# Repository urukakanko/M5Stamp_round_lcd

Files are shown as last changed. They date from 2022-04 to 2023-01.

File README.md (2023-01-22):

# M5Stampラウンド液晶モジュール

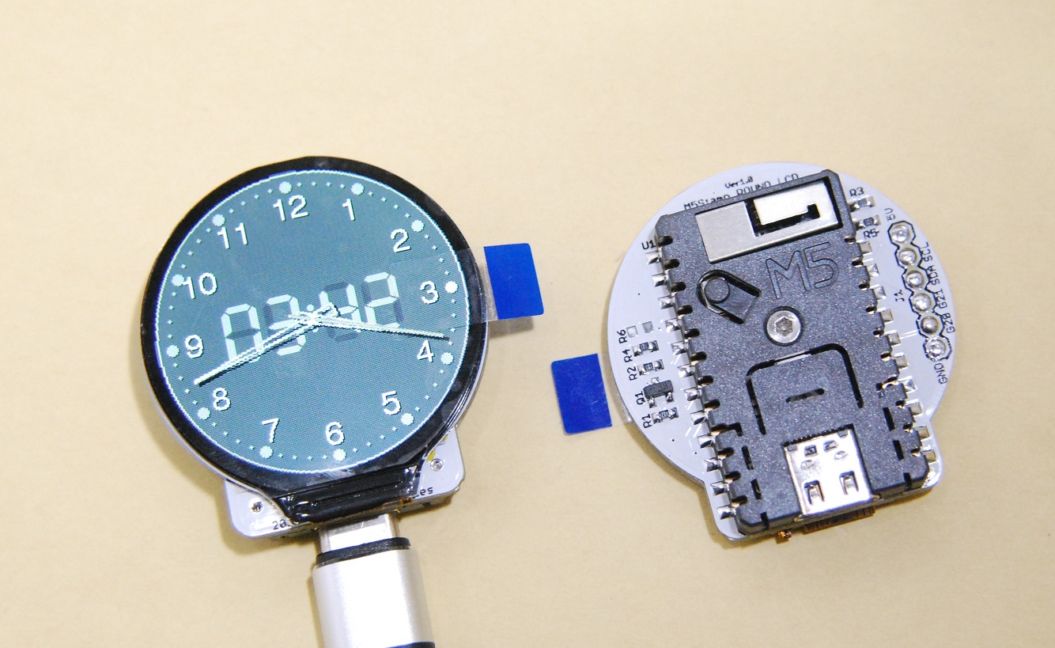
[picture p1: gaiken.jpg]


M5Stampを使用して1.28インチ240ｘ240ドットの円形液晶を駆動する基板モジュールです。

円形液晶の裏にM5Stampを配置することで、とても小さくスリムな形状になりました。

円形液晶にはGC9A01というコントローラーが使用されていますが、対応したグラフィックライブラリが数種類公開されています。

本モジュールは「グラフィックライブラリの使い方を理解して液晶モジュールを駆動出来る人」をターゲットにしております。

# <span style="color: red;">注意！！（必ずお読み下さい）</span>

本品は基本的な電子回路の仕組みを理解した方を対象とした、電子部品がむき出しの半完成キットです。
電子部品は電源電圧や極性を間違えたり、部品を破損させたり部品端子をショートさせた場合、発熱・発煙・発火に至る場合もあります。
間違った使い方をすると危険である事を理解された方のみご使用ください。
趣味の電子工作向けに製作しておりますので、製品への組込みや日常生活へ組込んでのご使用はお控え下さい。

# 形状および回路図

以下に外形イメージを示します

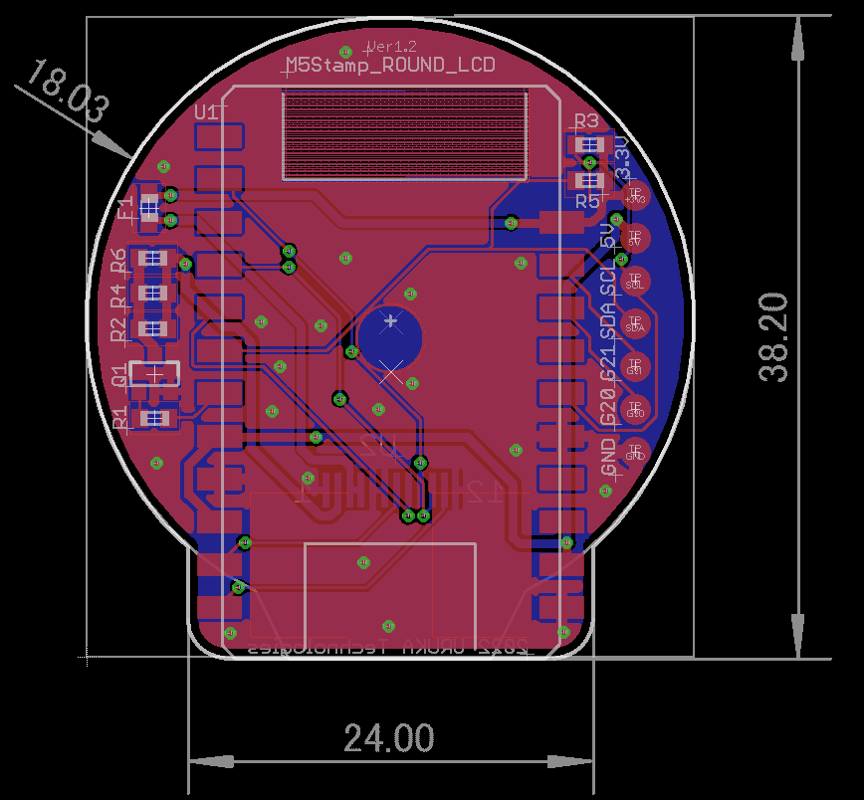
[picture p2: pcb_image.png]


以下に回路図を示します　現在最新は基板Ver1.2です

　基板Ver1.0の回路図などはこちら⇒
https://github.com/urukakanko/M5Stamp_round_lcd/tree/main/Ver1.0

　基板Ver1.1の回路図などはこちら⇒
https://github.com/urukakanko/M5Stamp_round_lcd/tree/main/Ver1.1

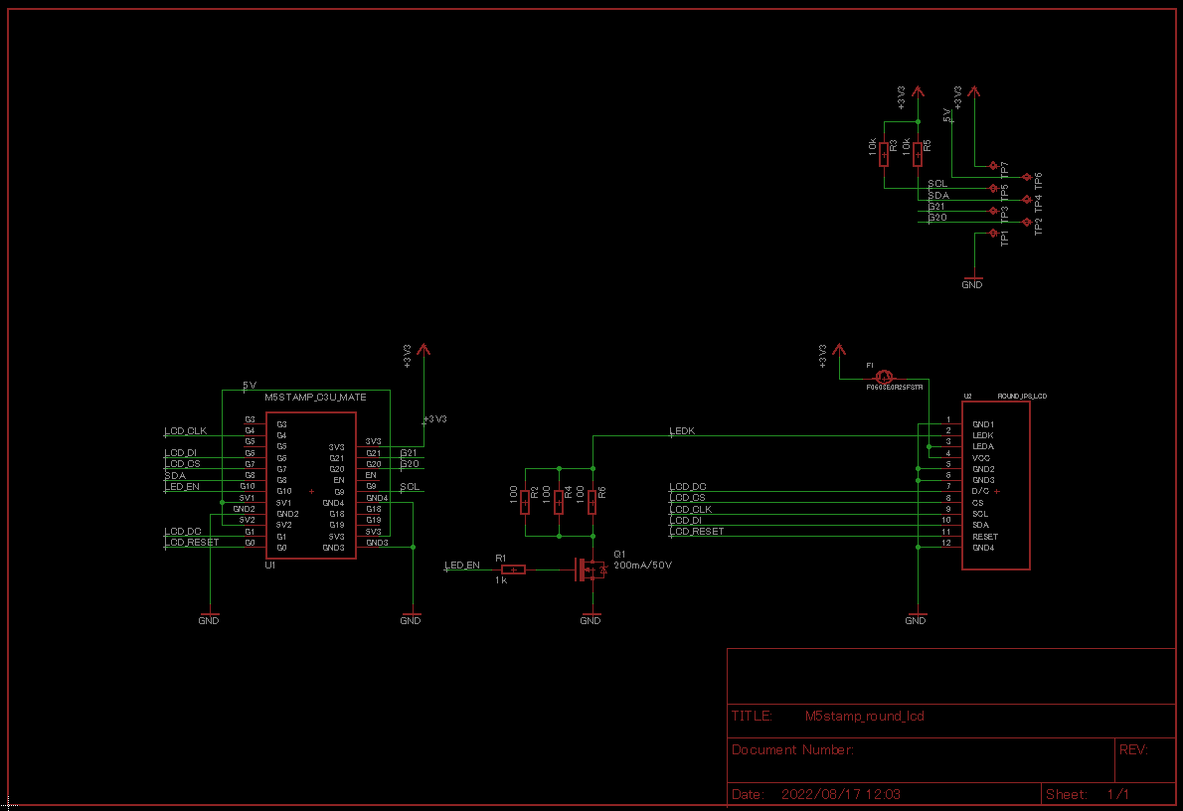
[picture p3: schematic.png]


# ピンアサイン

M5Stamp とLCDの制御信号とのピン接続は以下となります。

- SCLK:G4

- MOSI:G6

- DC:G1

- CS:G7

- RST:G0

- バックライト:G10　バックライトLEDのPIN設定は必ず行ってください。ハイインピーダンスとなった場合バックライトが不安定になります。

また、I2C接続などを想定した外部接続端子があります

注意：リード線をハンダ付けするパットとして使用します　コネクタやピンヘッダは挿せません。　基板Ver1.0ではスルーホールになっていますが無理やり挿すとピン先がLCDにぶつかって破損したりショートする恐れがあります。
また、6PINおよび7PINはセンサーなど小型周辺モジュールを駆動するための電源出力端子です。本モジュールを駆動するための電源入力としては設計しておりません。

- 1PIN : GND

- 2PIN : G20

- 3PIN : G21

- 4PIN : G8 (I2C SDAを想定)

- 5PIN : G9 (I2C SCLを想定)

- 6PIN : 5V

- 7PIN : 3.3V(基板Ver1.0にはありません　基板Ver1.1より対応) 

「M5Stamp C3U」　および　「 M5Stamp C3」　両方が使用出来る様にG3端子は未接続にしています

# 使用するツールやライブラリ

M5StampのArduino IDEへのインストールは、以下サイトを参考下さい。

https://docs.m5stack.com/en/quick_start/m5core/arduino

グラフィックライブラリについてはlovyanさまのLovyanGFXにて動作確認をしています。

https://github.com/lovyan03/LovyanGFX

他、GC9A01に対応したライブラリが使用可能と考えています。

# そーたメイさま「つくるっち」に対応して頂きました

http://sohta02.web.fc2.com/familyday.html

事前に以下ツールでM5Stampラウンド液晶モジュールにファームウェアを書込んでください

https://sohta02.sakura.ne.jp/release/burnESP.20220930.zip

Chromeブラウザで以下つくるっち画面を開き「拡張機能を追加」から「M5Series」を追加してください

https://sohta02.sakura.ne.jp/tukurutch/

サンプルプログラムは以下です

https://github.com/urukakanko/M5Stamp_round_lcd/blob/main/M5Stamp%E3%82%B5%E3%83%B3%E3%83%97%E3%83%AB_%E3%83%8F%E3%83%83%E3%83%94%E3%83%BC%E3%83%8F%E3%83%AD%E3%82%A6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

USB接続で以下の様に動かす事ができます

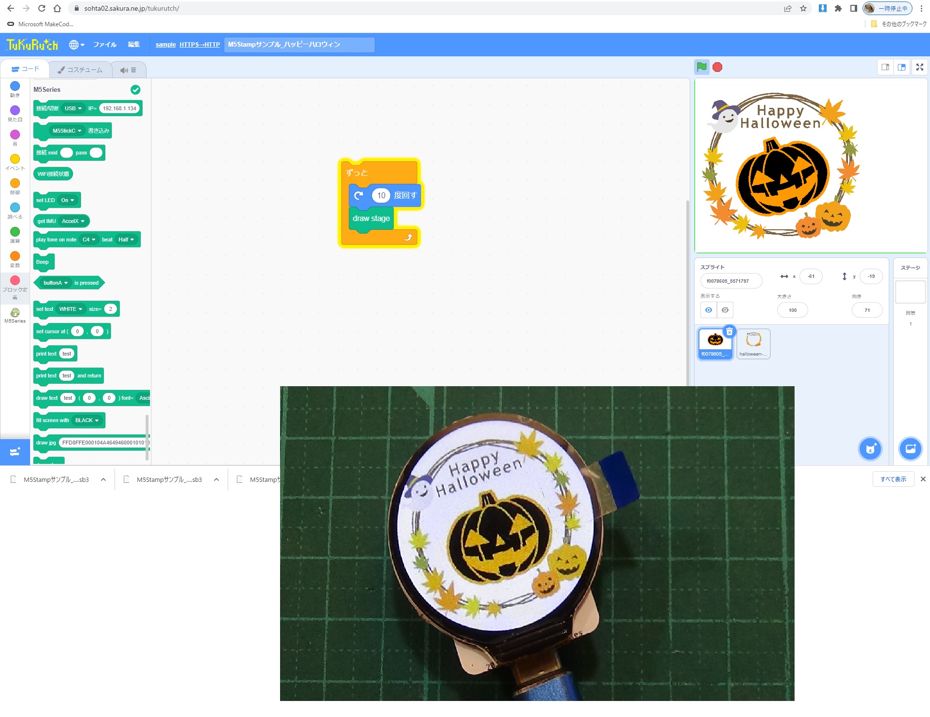
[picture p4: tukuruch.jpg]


もちろんWiFiでの動作も可能です。詳細設定についてはそーたメイさまのサイトを参考にしてください

説明内のファームウェア書き込み操作は不要です【ファームウェア書き込み： マイコンを選択して [書き込み] をクリック】

http://sohta02.web.fc2.com/familyday_app3.html#setup_esp32

# LCD表示動画

https://youtu.be/kj006jx1wdU

# 製作過程動画

https://youtu.be/ezlkv9BLLXo

# 使用例

スマートウォッチはもちろん、アイコン表示でカードフォルダー代わり

ロボットに顔写真を表示すると、とても味のある雰囲気に・・・

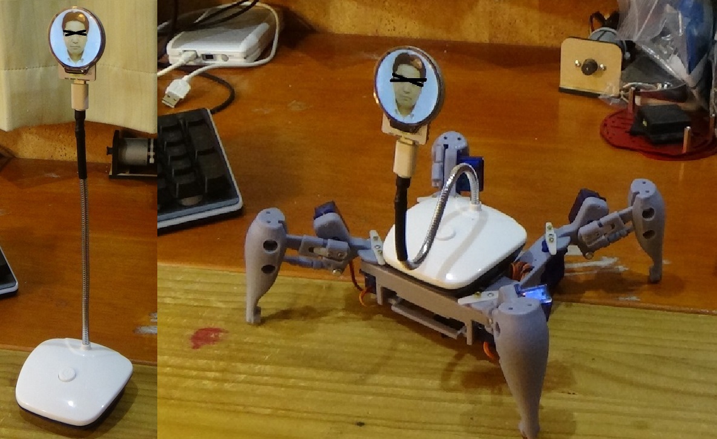
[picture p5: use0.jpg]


AMG8833と組合わせると温度虫眼鏡も作れます　動画はこちら
https://youtu.be/yjvwYW8tv_Q
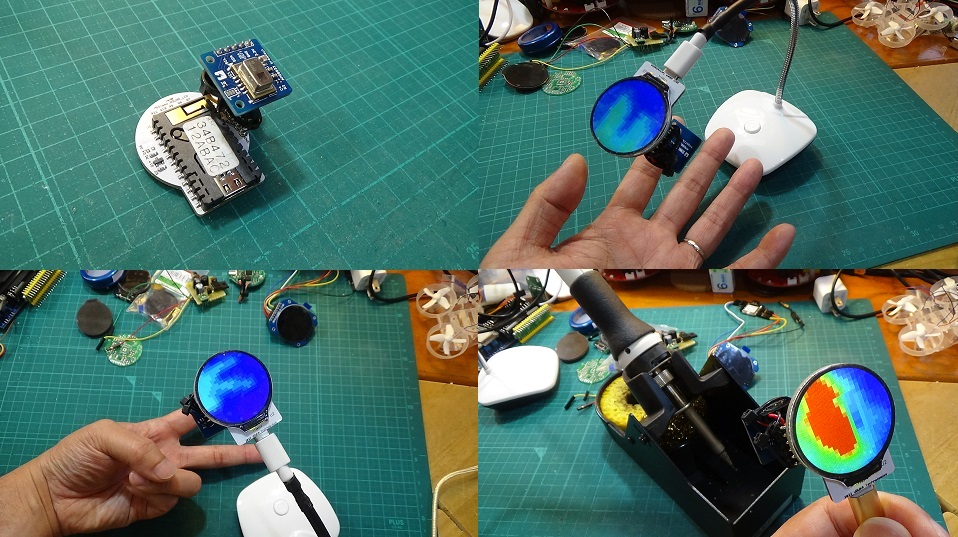
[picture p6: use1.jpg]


AMG8833サーマルカメラの作り方をまとめました　とても便利ですので興味がある方はご覧ください

https://github.com/urukakanko/M5Stamp_round_lcd/tree/main/thermal_cam_demo

カラフルな液晶バッジ

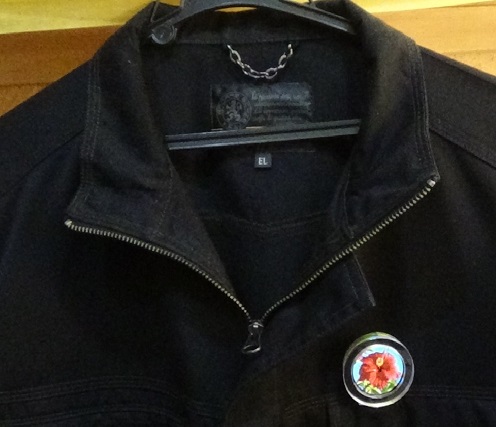
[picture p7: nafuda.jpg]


# スイッチサイエンスマーケットプレイスで販売しています
M5Stamp実装版
https://www.switch-science.com/catalog/8098/

M5Stamp未実装版
https://www.switch-science.com/catalog/8099/

# 製作者

ウルカテクノロジー
Hiroyuki Sunagawa

https://www.facebook.com/URUKA-Technologies-105478404379918

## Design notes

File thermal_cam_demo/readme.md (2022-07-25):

# M5Stampラウンド液晶モジュール作例　AMG8833サーマルカメラ

電子工作をしていると異常発熱する部品があったりしてサーモグラフィーで観察したくなる場合があります。

でもそんな高級品はなかなか買えません。そんなときAMG8833を使用した簡易サーマルカメラが役に立ちます。

AMG8833はパナソニック製の８ｘ８セルのサーマルセンサーです。I2Cインターフェースで制御します。

なお、AMG8833自体を詳しく弄りたい方はこちらを購入するとよいと思います。

https://www.switch-science.com/catalog/3498/

## ハードの作り方

AMG8833モジュールを入手します。スイッチサイエンスや秋月電子で入手が可能です。

今回はスイッチサイエンスで販売しているモジュールが手元にあったのでそれで作ってみます

以下の様にAMG8833モジュールにリード線をハンダ付けします

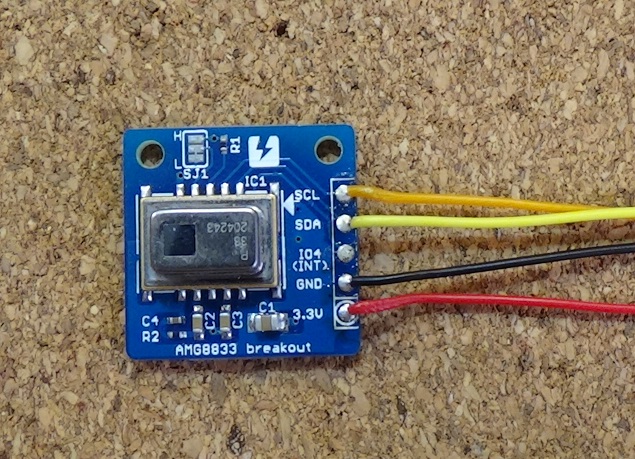
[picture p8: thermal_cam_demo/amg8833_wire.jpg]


必要な接続線は、３．３V、GND、SDA、SCL　の４本です。リード線を使ってAMG8833モジュールとM5Stampラウンド液晶モジュールをつなげます。

裏面を念のためにテープ等で絶縁しています。ポリイミドテープ（カプトンテープ）がお勧めです

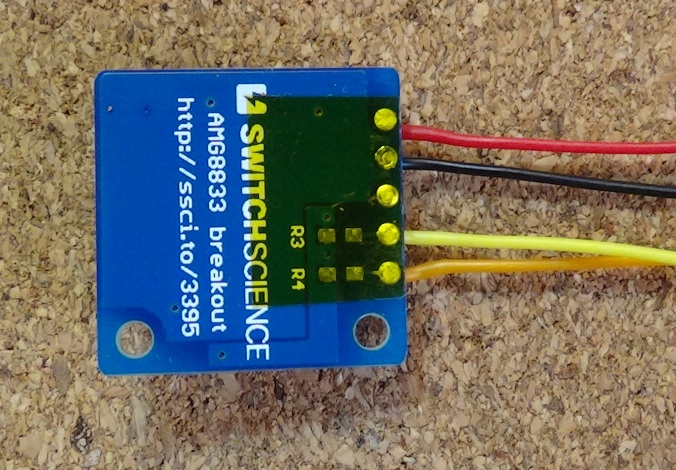
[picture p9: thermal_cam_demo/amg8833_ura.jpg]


リード線の反対側をM5Stampラウンド液晶モジュールに結線します。

M5Stampラウンド液晶モジュールVer1.0の場合は3.3Vパットを出していないので、M5Stampの端子に直接リード線をハンダ付けします。

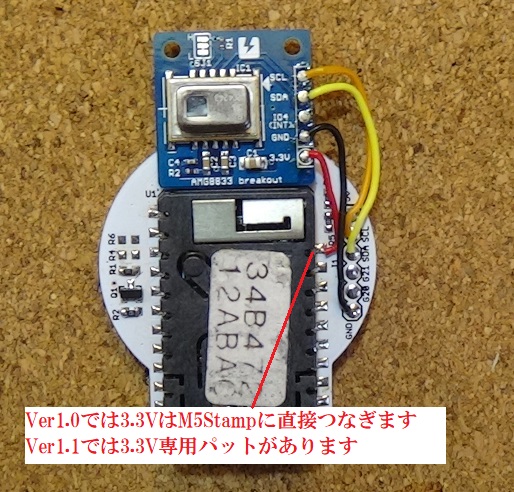
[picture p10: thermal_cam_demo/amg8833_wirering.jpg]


M5Stampに両面テープを貼り、そこにAMG8833モジュールを貼り付けます

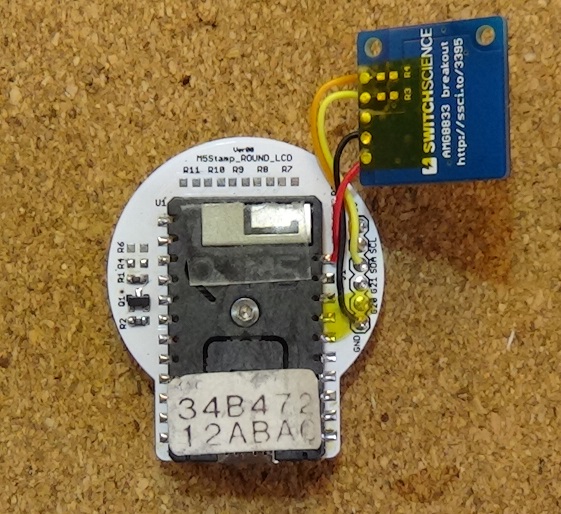
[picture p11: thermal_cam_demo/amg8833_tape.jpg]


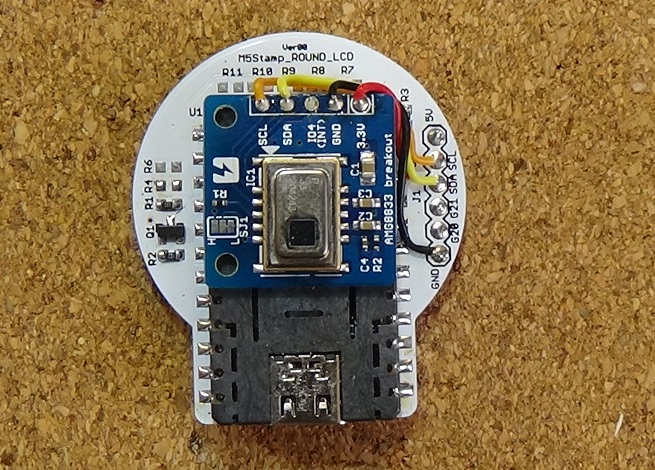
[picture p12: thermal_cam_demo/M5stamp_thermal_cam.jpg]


## プログラミング

Arduino IDEでプログラミングします。

今回AMG8833を駆動させるために、Adafruit AMG88xx Library　を使用します。

スケッチ⇒ライブラリをインクルード⇒ライブラリを管理　でライブラリマネージャを開き　Adafruit AMG88xxで検索します

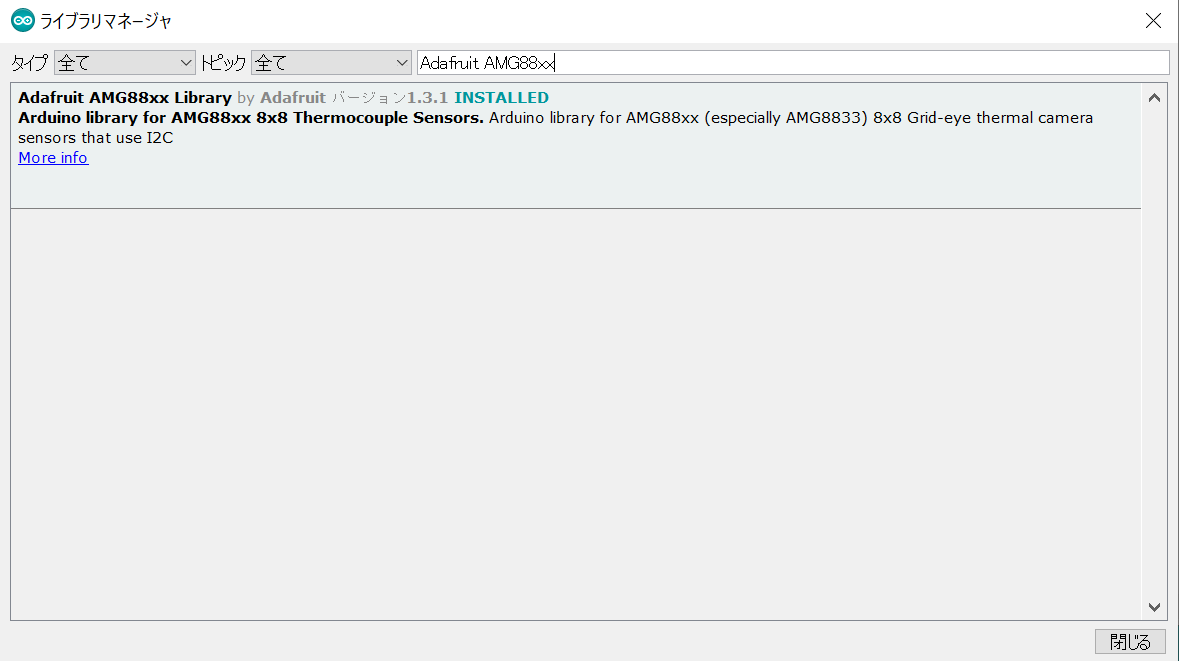
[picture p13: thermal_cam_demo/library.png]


ライブラリをインストールしたら、スケッチの例を呼び出します。

AMG8833をTFT液晶に表示するスケッチ例「thermal_cam_interpolate.ino」が準備されてましたので使用しました。

ただし使用する液晶が異なる事、表示位置のオフセット、補完内容の変更などがあるので修正が必要となります。

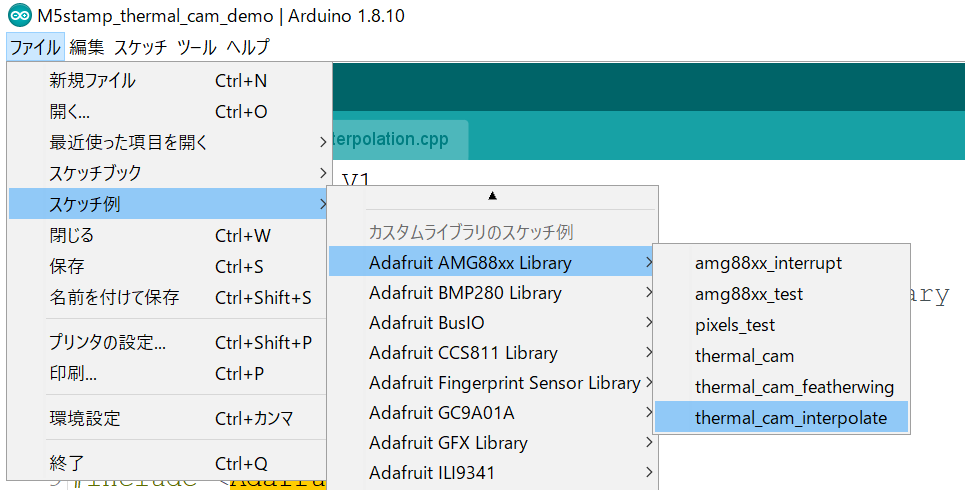
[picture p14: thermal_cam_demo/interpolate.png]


修正後のソースコードは以下に保存しています。

https://github.com/urukakanko/M5Stamp_round_lcd/tree/main/thermal_cam_demo/M5stamp_thermal_cam_demo/M5stamp_thermal_cam_demo

### ソースコード修正のポイント説明

#### 液晶設定と液晶ライブラリについて

スケッチ例では使用する液晶がILI9341になっているのでGC9A01に直す必要があります。

また使用する液晶ライブラリはAdafruit_GFXになっています。　このライブラリでGC9A01も駆動可能なのですが動作速度がちょっと遅かったです。解像度を上げると厳しいので高速化のためにLavyanGFXを使用しています。

ソースコードの先頭から94行目まで入れ替えてあります。

#### 補完について

AMG8833は　8x8(64)セル　のサーマルセンサーなので、このまま映像化しても粗いモザイクの画像になります。そこで補完計算を行い解像の高い画像にしています。

ただし解像度を高くするほど計算に時間がかかってしまいますので表示速度の頃合いをみて40x40にしています。

ソースコード136行目と137行目で設定しています

　#define INTERPOLATED_COLS 40
　#define INTERPOLATED_ROWS 40

#### その他

AMG8833のI2Cアドレスは159行目で0x68に指定しています。必要に応じて0x69にしてください。

液晶の解像度自体が元とは異なるので表示位置を調整しています。

円型液晶は表示領域が狭いので、凡例表示は無しにしました。

## 動作イメージ

100円ショップのLEDライトスタンドを改造したラウンド液晶スタンドに取り付けてみました。

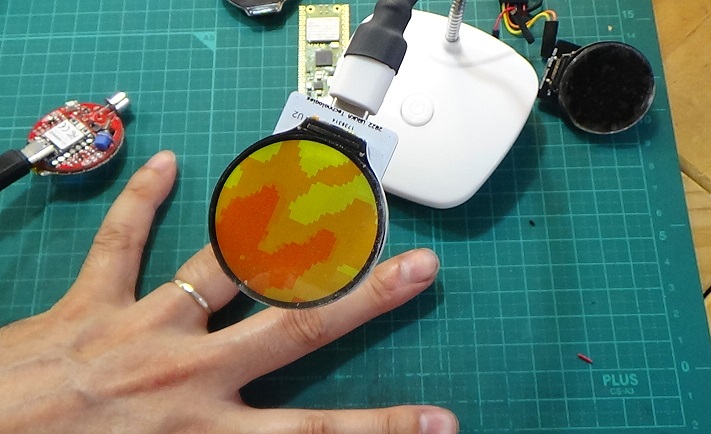
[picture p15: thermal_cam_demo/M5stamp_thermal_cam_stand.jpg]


手の形がなんとか見えるという感じです。

ラズベリーパイ４＋OpenCVで取得できる画像と比較するときついけど、常に持ち歩いて必要な時に即座に使うとか出来るので利便性はとても良いです。

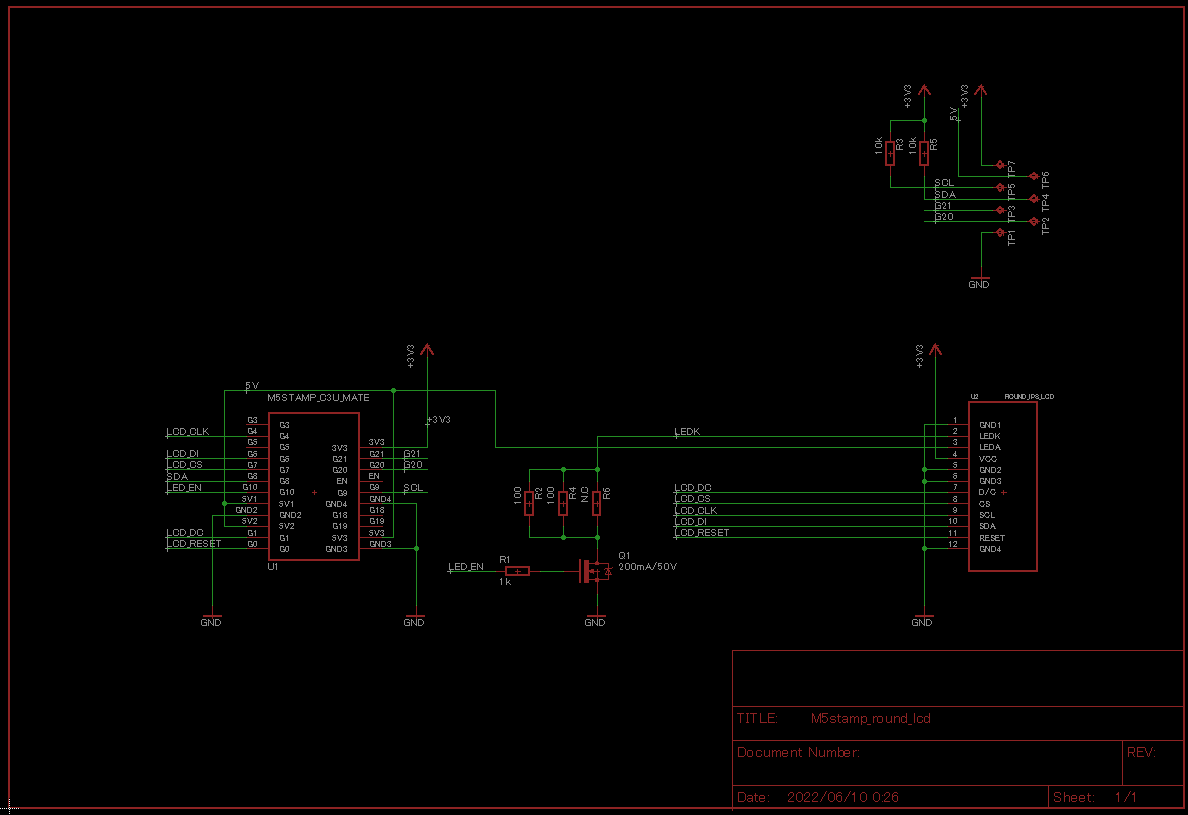
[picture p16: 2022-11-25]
Ver1.1/schematic.png

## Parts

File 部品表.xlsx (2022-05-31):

Part | Value | Device
J1 | 6PIN
Q1 | 200mA/50V | BSS138
R1 | 1k | 1608
R2 | 100 | 1608
R3 | 10k | 1608
R4 | 100 | 1608
R5 | 10k | 1608
R6 | N.C | 1608
U1 | M5STAMP_C3U_MATE | M5STAMP_C3U_MATE
U2 | ROUND_IPS_LCD | ROUND_IPS_LCD

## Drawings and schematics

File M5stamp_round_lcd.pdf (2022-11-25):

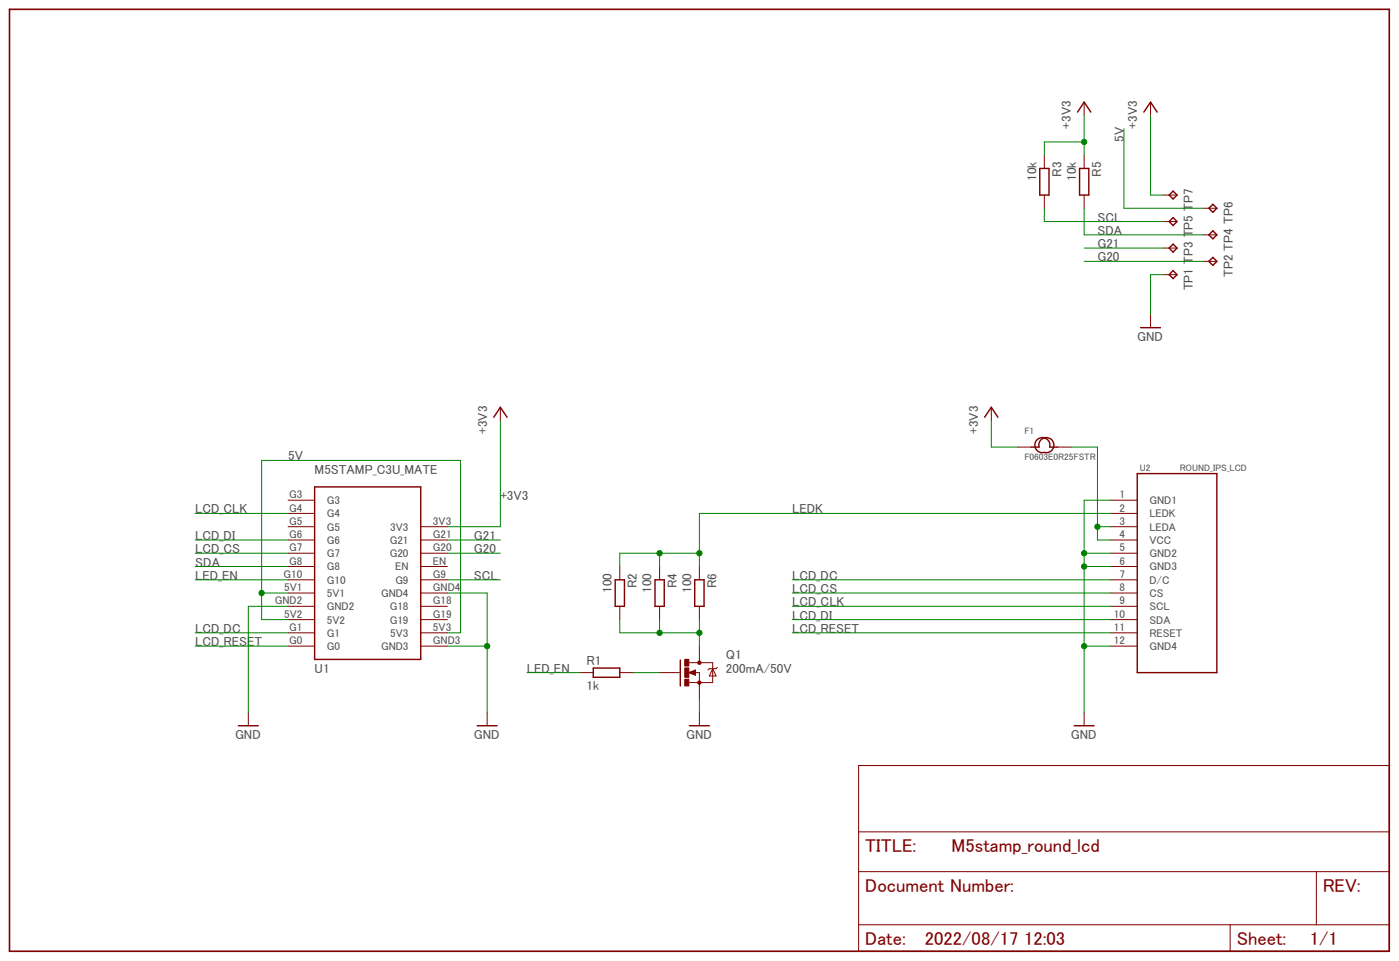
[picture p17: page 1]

Document Number: | REV:

Date: 2022/08/17 12:03 | Sheet: 1/1

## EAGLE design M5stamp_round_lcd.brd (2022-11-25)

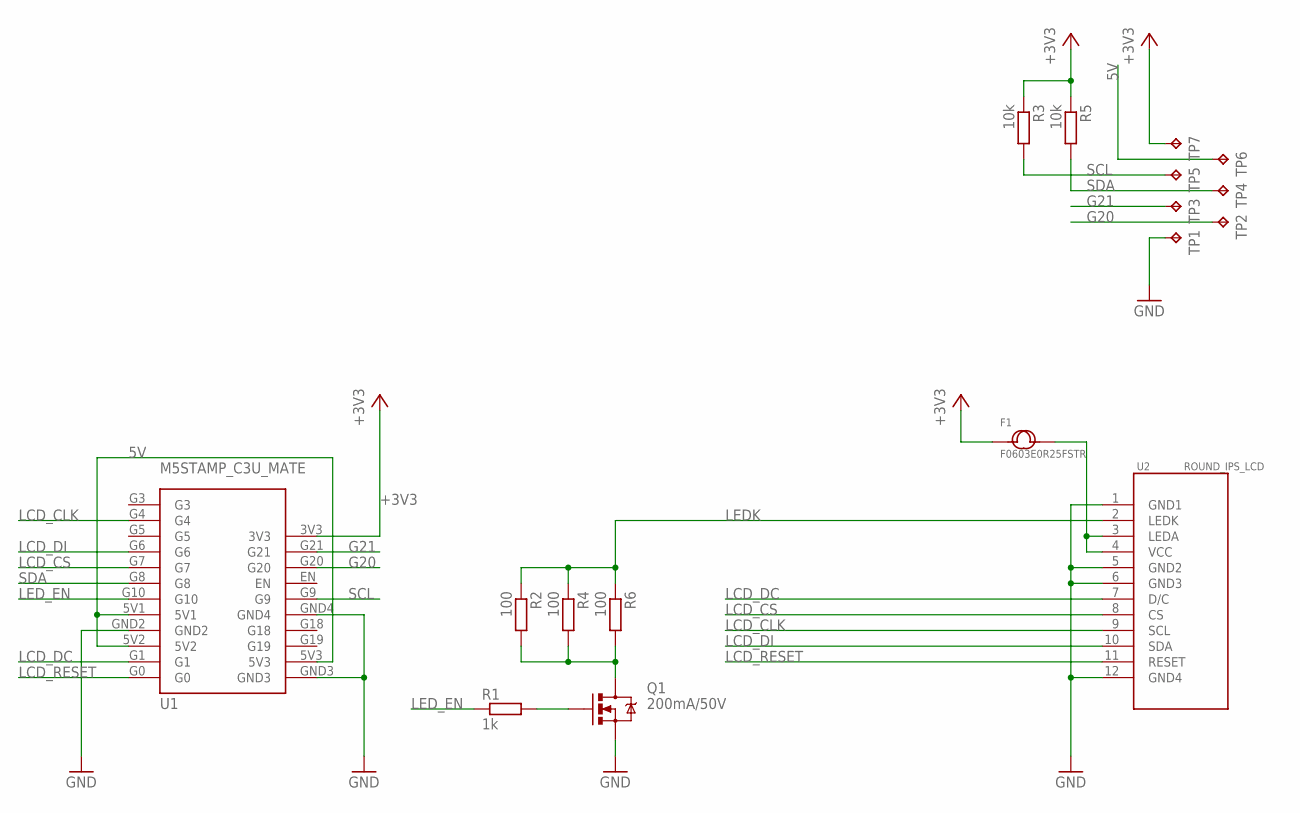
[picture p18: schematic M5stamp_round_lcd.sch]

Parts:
F1: F0603E0R25FSTR; C0603
Q1: 200mA/50V; SOT23-3
R1: 1k; R0603
R2, R4, R6: 100; R0603
R3, R5: 10k; R0603
TP1, TP2, TP3, TP4, TP5, TP6, TP7: TPTP18R; TP18R
U1: M5STAMP_C3U_MATE; M5STAMPC3UMATE
U2: ROUND_IPS_LCD

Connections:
5V: TP6.TP, U1.5V1, U1.5V2, U1.5V3
+3V3: F1.1, R3.1, R5.1, TP7.TP, U1.3V3
G20: TP2.TP, U1.G20
G21: TP3.TP, U1.G21
GND: Q1.2 (S), TP1.TP, U1.GND2, U1.GND3, U1.GND4, U2.1 (GND1), U2.5 (GND2), U2.6 (GND3), U2.12 (GND4)
LCD_CLK: U1.G4, U2.9 (SCL)
LCD_CS: U1.G7, U2.8 (CS)
LCD_DC: U1.G1, U2.7 (D/C)
LCD_DI: U1.G6, U2.10 (SDA)
LCD_RESET: U1.G0, U2.11 (RESET)
LEDK: R2.1, R4.1, R6.1, U2.2 (LEDK)
LED_EN: R1.1, U1.G10
unnamed: Q1.3 (D), R2.2, R4.2, R6.2
unnamed: Q1.1 (G), R1.2
unnamed: F1.2, U2.3 (LEDA), U2.4 (VCC)
SCL: R3.2, TP5.TP, U1.G9
SDA: R5.2, TP4.TP, U1.G8

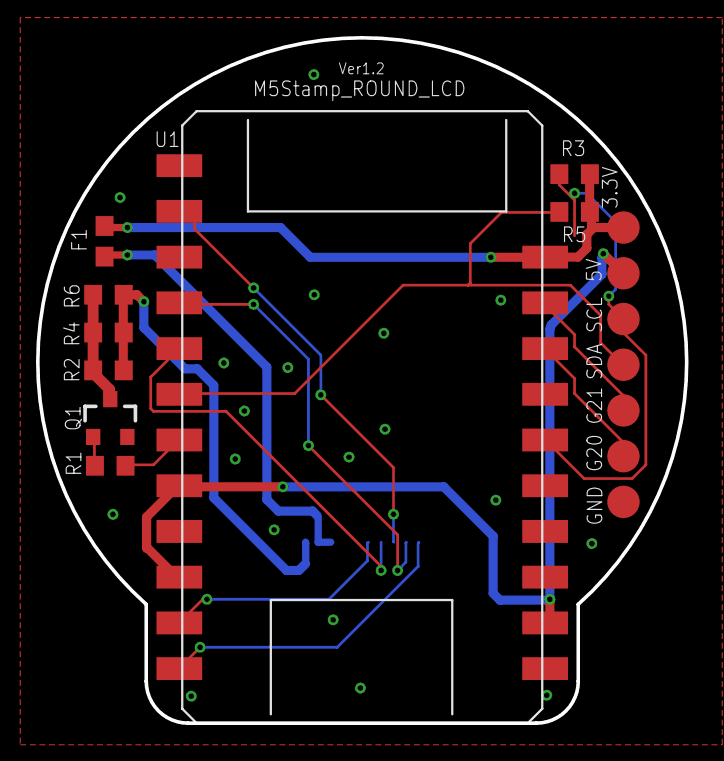
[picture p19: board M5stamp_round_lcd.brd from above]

Board: 2 copper layers, 36.0 x 38.1 mm, 17 parts (1 on the bottom side), 17 nets.

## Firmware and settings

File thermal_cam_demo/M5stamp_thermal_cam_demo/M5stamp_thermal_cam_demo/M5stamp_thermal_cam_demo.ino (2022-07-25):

/***************************************************************************
  This is a library for the AMG88xx GridEYE 8x8 IR camera

  This sketch makes an inetrpolated pixel thermal camera with the 
  GridEYE sensor and a 2.4" tft featherwing:
	 https://www.adafruit.com/product/3315

  Designed specifically to work with the Adafruit AMG8833 Featherwing
          https://www.adafruit.com/product/3622

  These sensors use I2C to communicate. The device's I2C address is 0x69

  Adafruit invests time and resources providing this open source code,
  please support Adafruit andopen-source hardware by purchasing products
  from Adafruit!

  Written by Dean Miller, James DeVito & ladyada for Adafruit Industries.
  BSD license, all text above must be included in any redistribution
 ***************************************************************************/



#define LGFX_USE_V1
#include <LovyanGFX.hpp>

//#include <Adafruit_GFX.h>    // Core graphics library
//#include <SPI.h>
//#include "Adafruit_GC9A01A.h"

#include <Wire.h>
#include <Adafruit_AMG88xx.h>
#define TFT_CS   7
#define TFT_DC   1
#define TFT_CLK  4
#define TFT_DI   6
#define TFT_RST  0
#define TFT_BL  10
#define I2C_SDA  8
#define I2C_SCL  9

//Comment this out to remove the text overlay
//#define SHOW_TEMP_TEXT

//low range of the sensor (this will be blue on the screen)
#define MINTEMP 10

//high range of the sensor (this will be red on the screen)
#define MAXTEMP 30

class LGFX_M5Stamp_SPI_GC9A01 : public lgfx::LGFX_Device
{
lgfx::Panel_GC9A01      _panel_instance;
lgfx::Bus_SPI       _bus_instance;   // SPIバスのインスタンス
lgfx::Light_PWM     _light_instance;
public:
  LGFX_M5Stamp_SPI_GC9A01(void)
  {
    { // バス制御の設定を行います。
      auto cfg = _bus_instance.config();    // バス設定用の構造体を取得します。

// SPIバスの設定
      cfg.spi_host = SPI2_HOST;     // 使用するSPIを選択  ESP32-S2,C3 : SPI2_HOST or SPI3_HOST / ESP32 : VSPI_HOST or HSPI_HOST
      // ※ ESP-IDFバージョンアップに伴い、VSPI_HOST , HSPI_HOSTの記述は非推奨になるため、エラーが出る場合は代わりにSPI2_HOST , SPI3_HOSTを使用してください。
      cfg.spi_mode = 0;             // SPI通信モードを設定 (0 ~ 3)
      cfg.freq_write = 40000000;    // 送信時のSPIクロック (最大80MHz, 80MHzを整数で割った値に丸められます)
      cfg.freq_read  = 16000000;    // 受信時のSPIクロック
      cfg.spi_3wire  = true;        // 受信をMOSIピンで行う場合はtrueを設定
      cfg.use_lock   = true;        // トランザクションロックを使用する場合はtrueを設定
      cfg.dma_channel = SPI_DMA_CH_AUTO; // 使用するDMAチャンネルを設定 (0=DMA不使用 / 1=1ch / 2=ch / SPI_DMA_CH_AUTO=自動設定)
      // ※ ESP-IDFバージョンアップに伴い、DMAチャンネルはSPI_DMA_CH_AUTO(自動設定)が推奨になりました。1ch,2chの指定は非推奨になります。
      cfg.pin_sclk = 4;            // SPIのSCLKピン番号を設定
      cfg.pin_mosi = 6;            // SPIのMOSIピン番号を設定
      cfg.pin_miso = -1;            // SPIのMISOピン番号を設定 (-1 = disable)
      cfg.pin_dc   = 1;            // SPIのD/Cピン番号を設定  (-1 = disable)
     // SDカードと共通のSPIバスを使う場合、MISOは省略せず必ず設定してください。
      _bus_instance.config(cfg);    // 設定値をバスに反映します。
      _panel_instance.setBus(&_bus_instance);      // バスをパネルにセットします。
    }

    { // 表示パネル制御の設定を行います。
      auto cfg = _panel_instance.config();    // 表示パネル設定用の構造体を取得します。
      cfg.pin_cs           =    7;  // CSが接続されているピン番号   (-1 = disable)
      cfg.pin_rst          =    0;  // RSTが接続されているピン番号  (-1 = disable)
      cfg.pin_busy         =    -1;  // BUSYが接続されているピン番号 (-1 = disable)
      // ※ 以下の設定値はパネル毎に一般的な初期値が設定されていますので、不明な項目はコメントアウトして試してみてください。
      cfg.memory_width     =   240;  // ドライバICがサポートしている最大の幅
      cfg.memory_height    =   240;  // ドライバICがサポートしている最大の高さ
      cfg.panel_width      =   240;  // 実際に表示可能な幅
      cfg.panel_height     =   240;  // 実際に表示可能な高さ
      cfg.offset_x         =     0;  // パネルのX方向オフセット量
      cfg.offset_y         =     0;  // パネルのY方向オフセット量
      cfg.offset_rotation  =     0;  // 回転方向の値のオフセット 0~7 (4~7は上下反転)
      cfg.dummy_read_pixel =     8;  // ピクセル読出し前のダミーリードのビット数
      cfg.dummy_read_bits  =     1;  // ピクセル以外のデータ読出し前のダミーリードのビット数
      cfg.readable         =  true;  // データ読出しが可能な場合 trueに設定
      cfg.invert           =  true;  // パネルの明暗が反転してしまう場合 trueに設定
      cfg.rgb_order        = false;  // パネルの赤と青が入れ替わってしまう場合 trueに設定
      cfg.dlen_16bit       = false;  // データ長を16bit単位で送信するパネルの場合 trueに設定
      cfg.bus_shared       =  true;  // SDカードとバスを共有している場合 trueに設定(drawJpgFile等でバス制御を行います)

      _panel_instance.config(cfg);
    }
    { // バックライト制御の設定を行います。（必要なければ削除）
      auto cfg = _light_instance.config();    // バックライト設定用の構造体を取得します。

      cfg.pin_bl = 10;              // バックライトが接続されているピン番号
      cfg.invert = false;           // バックライトの輝度を反転させる場合 true
      cfg.freq   = 44100;           // バックライトのPWM周波数
      cfg.pwm_channel = 3;          // 使用するPWMのチャンネル番号

      _light_instance.config(cfg);
      _panel_instance.setLight(&_light_instance);  // バックライトをパネルにセットします。
    }
    setPanel(&_panel_instance); // 使用するパネルをセットします。
  }
};


//the colors we will be using
const uint16_t camColors[] = {0x480F,
0x400F,0x400F,0x400F,0x4010,0x3810,0x3810,0x3810,0x3810,0x3010,0x3010,
0x3010,0x2810,0x2810,0x2810,0x2810,0x2010,0x2010,0x2010,0x1810,0x1810,
0x1811,0x1811,0x1011,0x1011,0x1011,0x0811,0x0811,0x0811,0x0011,0x0011,
0x0011,0x0011,0x0011,0x0031,0x0031,0x0051,0x0072,0x0072,0x0092,0x00B2,
0x00B2,0x00D2,0x00F2,0x00F2,0x0112,0x0132,0x0152,0x0152,0x0172,0x0192,
0x0192,0x01B2,0x01D2,0x01F3,0x01F3,0x0213,0x0233,0x0253,0x0253,0x0273,
0x0293,0x02B3,0x02D3,0x02D3,0x02F3,0x0313,0x0333,0x0333,0x0353,0x0373,
0x0394,0x03B4,0x03D4,0x03D4,0x03F4,0x0414,0x0434,0x0454,0x0474,0x0474,
0x0494,0x04B4,0x04D4,0x04F4,0x0514,0x0534,0x0534,0x0554,0x0554,0x0574,
0x0574,0x0573,0x0573,0x0573,0x0572,0x0572,0x0572,0x0571,0x0591,0x0591,
0x0590,0x0590,0x058F,0x058F,0x058F,0x058E,0x05AE,0x05AE,0x05AD,0x05AD,
0x05AD,0x05AC,0x05AC,0x05AB,0x05CB,0x05CB,0x05CA,0x05CA,0x05CA,0x05C9,
0x05C9,0x05C8,0x05E8,0x05E8,0x05E7,0x05E7,0x05E6,0x05E6,0x05E6,0x05E5,
0x05E5,0x0604,0x0604,0x0604,0x0603,0x0603,0x0602,0x0602,0x0601,0x0621,
0x0621,0x0620,0x0620,0x0620,0x0620,0x0E20,0x0E20,0x0E40,0x1640,0x1640,
0x1E40,0x1E40,0x2640,0x2640,0x2E40,0x2E60,0x3660,0x3660,0x3E60,0x3E60,
0x3E60,0x4660,0x4660,0x4E60,0x4E80,0x5680,0x5680,0x5E80,0x5E80,0x6680,
0x6680,0x6E80,0x6EA0,0x76A0,0x76A0,0x7EA0,0x7EA0,0x86A0,0x86A0,0x8EA0,
0x8EC0,0x96C0,0x96C0,0x9EC0,0x9EC0,0xA6C0,0xAEC0,0xAEC0,0xB6E0,0xB6E0,
0xBEE0,0xBEE0,0xC6E0,0xC6E0,0xCEE0,0xCEE0,0xD6E0,0xD700,0xDF00,0xDEE0,
0xDEC0,0xDEA0,0xDE80,0xDE80,0xE660,0xE640,0xE620,0xE600,0xE5E0,0xE5C0,
0xE5A0,0xE580,0xE560,0xE540,0xE520,0xE500,0xE4E0,0xE4C0,0xE4A0,0xE480,
0xE460,0xEC40,0xEC20,0xEC00,0xEBE0,0xEBC0,0xEBA0,0xEB80,0xEB60,0xEB40,
0xEB20,0xEB00,0xEAE0,0xEAC0,0xEAA0,0xEA80,0xEA60,0xEA40,0xF220,0xF200,
0xF1E0,0xF1C0,0xF1A0,0xF180,0xF160,0xF140,0xF100,0xF0E0,0xF0C0,0xF0A0,
0xF080,0xF060,0xF040,0xF020,0xF800,};

//Adafruit_GC9A01A tft = Adafruit_GC9A01A(TFT_CS, TFT_DC,TFT_DI,TFT_CLK,TFT_RST);
LGFX_M5Stamp_SPI_GC9A01 tft;

Adafruit_AMG88xx amg;
unsigned long delayTime;

#define AMG_COLS 8
#define AMG_ROWS 8
float pixels[AMG_COLS * AMG_ROWS];

#define INTERPOLATED_COLS 40
#define INTERPOLATED_ROWS 40

float get_point(float *p, uint8_t rows, uint8_t cols, int8_t x, int8_t y);
void set_point(float *p, uint8_t rows, uint8_t cols, int8_t x, int8_t y, float f);
void get_adjacents_1d(float *src, float *dest, uint8_t rows, uint8_t cols, int8_t x, int8_t y);
void get_adjacents_2d(float *src, float *dest, uint8_t rows, uint8_t cols, int8_t x, int8_t y);
float cubicInterpolate(float p[], float x);
float bicubicInterpolate(float p[], float x, float y);
void interpolate_image(float *src, uint8_t src_rows, uint8_t src_cols, 
                       float *dest, uint8_t dest_rows, uint8_t dest_cols);
void setup() {
  pinMode(TFT_BL,OUTPUT);
  digitalWrite(TFT_BL,HIGH);
  Serial.begin(115200);  
  Serial.println("\n\nAMG88xx Interpolated Thermal Camera!");

  tft.init();
  //tft.begin();
  tft.setRotation(0);
  tft.fillScreen(TFT_BLACK);

  Wire.begin(I2C_SDA,I2C_SCL);  
  if (!amg.begin(0x68)) {    
    Serial.println("Could not find a valid AMG88xx sensor, check wiring!");
    //while (1) { delay(1); }
  } 
  Serial.println("-- Thermal Camera Test --");
}

void loop() {
  //read all the pixels
  amg.readPixels(pixels);

  Serial.print("[");
  for(int i=1; i<=AMG88xx_PIXEL_ARRAY_SIZE; i++){
    Serial.print(pixels[i-1]);
    Serial.print(", ");
    if( i%8 == 0 ) Serial.println();
  }
  Serial.println("]");
  Serial.println();

  float dest_2d[INTERPOLATED_ROWS * INTERPOLATED_COLS];

  int32_t t = millis();
  interpolate_image(pixels, AMG_ROWS, AMG_COLS, dest_2d, INTERPOLATED_ROWS, INTERPOLATED_COLS);
  Serial.print("Interpolation took "); Serial.print(millis()-t); Serial.println(" ms");

  uint16_t boxsize = min(tft.width() / INTERPOLATED_COLS, tft.height() / INTERPOLATED_COLS);
  
  drawpixels(dest_2d, INTERPOLATED_ROWS, INTERPOLATED_COLS, boxsize, boxsize, false);

  //delay(50);
}

void drawpixels(float *p, uint8_t rows, uint8_t cols, uint8_t boxWidth, uint8_t boxHeight, boolean showVal) {
  int colorTemp;
  for (int y=0; y<rows; y++) {
    for (int x=0; x<cols; x++) {
      float val = get_point(p, rows, cols, x, y);
      if(val >= MAXTEMP) colorTemp = MAXTEMP;
      else if(val <= MINTEMP) colorTemp = MINTEMP;
      else colorTemp = val;
      
      uint8_t colorIndex = map(colorTemp, MINTEMP, MAXTEMP, 0, 255);
      colorIndex = (uint8_t)constrain((int16_t)colorIndex, (int16_t)0, (int16_t)255);
      //draw the pixels!
      uint16_t color;
      color = val * 2;
      tft.fillRect(boxWidth * x, boxHeight * y, boxWidth, boxHeight, camColors[colorIndex]);        
      if (showVal) {
        tft.setCursor(boxWidth * y + boxWidth/2 - 12, 40 + boxHeight * x + boxHeight/2 - 4);
        tft.setTextColor(TFT_WHITE);  tft.setTextSize(1);
        tft.print(val,1);
      }
    } 
  }
}

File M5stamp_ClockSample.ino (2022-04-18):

#define LGFX_USE_V1
#include <LovyanGFX.hpp>

class LGFX_M5Stamp_SPI_GC9A01 : public lgfx::LGFX_Device
{
lgfx::Panel_GC9A01      _panel_instance;
lgfx::Bus_SPI       _bus_instance;   // SPIバスのインスタンス
lgfx::Light_PWM     _light_instance;
public:
  LGFX_M5Stamp_SPI_GC9A01(void)
  {
    { // バス制御の設定を行います。
      auto cfg = _bus_instance.config();    // バス設定用の構造体を取得します。

// SPIバスの設定
      cfg.spi_host = SPI2_HOST;     // 使用するSPIを選択  ESP32-S2,C3 : SPI2_HOST or SPI3_HOST / ESP32 : VSPI_HOST or HSPI_HOST
      // ※ ESP-IDFバージョンアップに伴い、VSPI_HOST , HSPI_HOSTの記述は非推奨になるため、エラーが出る場合は代わりにSPI2_HOST , SPI3_HOSTを使用してください。
      cfg.spi_mode = 0;             // SPI通信モードを設定 (0 ~ 3)
      cfg.freq_write = 40000000;    // 送信時のSPIクロック (最大80MHz, 80MHzを整数で割った値に丸められます)
      cfg.freq_read  = 16000000;    // 受信時のSPIクロック
      cfg.spi_3wire  = true;        // 受信をMOSIピンで行う場合はtrueを設定
      cfg.use_lock   = true;        // トランザクションロックを使用する場合はtrueを設定
      cfg.dma_channel = SPI_DMA_CH_AUTO; // 使用するDMAチャンネルを設定 (0=DMA不使用 / 1=1ch / 2=ch / SPI_DMA_CH_AUTO=自動設定)
      // ※ ESP-IDFバージョンアップに伴い、DMAチャンネルはSPI_DMA_CH_AUTO(自動設定)が推奨になりました。1ch,2chの指定は非推奨になります。
      cfg.pin_sclk = 4;            // SPIのSCLKピン番号を設定
      cfg.pin_mosi = 6;            // SPIのMOSIピン番号を設定
      cfg.pin_miso = -1;            // SPIのMISOピン番号を設定 (-1 = disable)
      cfg.pin_dc   = 1;            // SPIのD/Cピン番号を設定  (-1 = disable)
     // SDカードと共通のSPIバスを使う場合、MISOは省略せず必ず設定してください。
      _bus_instance.config(cfg);    // 設定値をバスに反映します。
      _panel_instance.setBus(&_bus_instance);      // バスをパネルにセットします。
    }

    { // 表示パネル制御の設定を行います。
      auto cfg = _panel_instance.config();    // 表示パネル設定用の構造体を取得します。
      cfg.pin_cs           =    7;  // CSが接続されているピン番号   (-1 = disable)
      cfg.pin_rst          =    0;  // RSTが接続されているピン番号  (-1 = disable)
      cfg.pin_busy         =    -1;  // BUSYが接続されているピン番号 (-1 = disable)
      // ※ 以下の設定値はパネル毎に一般的な初期値が設定されていますので、不明な項目はコメントアウトして試してみてください。
      cfg.memory_width     =   240;  // ドライバICがサポートしている最大の幅
      cfg.memory_height    =   240;  // ドライバICがサポートしている最大の高さ
      cfg.panel_width      =   240;  // 実際に表示可能な幅
      cfg.panel_height     =   240;  // 実際に表示可能な高さ
      cfg.offset_x         =     0;  // パネルのX方向オフセット量
      cfg.offset_y         =     0;  // パネルのY方向オフセット量
      cfg.offset_rotation  =     0;  // 回転方向の値のオフセット 0~7 (4~7は上下反転)
      cfg.dummy_read_pixel =     8;  // ピクセル読出し前のダミーリードのビット数
      cfg.dummy_read_bits  =     1;  // ピクセル以外のデータ読出し前のダミーリードのビット数
      cfg.readable         =  true;  // データ読出しが可能な場合 trueに設定
      cfg.invert           =  true;  // パネルの明暗が反転してしまう場合 trueに設定
      cfg.rgb_order        = false;  // パネルの赤と青が入れ替わってしまう場合 trueに設定
      cfg.dlen_16bit       = false;  // データ長を16bit単位で送信するパネルの場合 trueに設定
      cfg.bus_shared       =  true;  // SDカードとバスを共有している場合 trueに設定(drawJpgFile等でバス制御を行います)

      _panel_instance.config(cfg);
    }
    { // バックライト制御の設定を行います。（必要なければ削除）
      auto cfg = _light_instance.config();    // バックライト設定用の構造体を取得します。

      cfg.pin_bl = 10;              // バックライトが接続されているピン番号
      cfg.invert = false;           // バックライトの輝度を反転させる場合 true
      cfg.freq   = 44100;           // バックライトのPWM周波数
      cfg.pwm_channel = 3;          // 使用するPWMのチャンネル番号

      _light_instance.config(cfg);
      _panel_instance.setLight(&_light_instance);  // バックライトをパネルにセットします。
    }
    setPanel(&_panel_instance); // 使用するパネルをセットします。
  }
};

LGFX_M5Stamp_SPI_GC9A01 lcd;

static LGFX_Sprite canvas(&lcd);       // オフスクリーン描画用バッファ
static LGFX_Sprite clockbase(&canvas); // 時計の文字盤パーツ
static LGFX_Sprite needle1(&canvas);   // 長針・短針パーツ
static LGFX_Sprite shadow1(&canvas);   // 長針・短針の影パーツ
static LGFX_Sprite needle2(&canvas);   // 秒針パーツ
static LGFX_Sprite shadow2(&canvas);   // 秒針の影パーツ

static constexpr uint64_t oneday = 86400000; // 1日 = 1000msec x 60sec x 60min x 24hour = 86400000
static uint64_t count = rand() % oneday;    // 現在時刻 (ミリ秒カウンタ)
static int32_t width = 239;             // 時計の縦横画像サイズ
static int32_t halfwidth = width >> 1;  // 時計盤の中心座標
static auto transpalette = 0;           // 透過色パレット番号
static float zoom;                      // 表示倍率

#ifdef min
#undef min
#endif

void setup(void)
{
  lcd.init();

  zoom = (float)(std::min(lcd.width(), lcd.height())) / width; // 表示が画面にフィットするよう倍率を調整

  lcd.setPivot(lcd.width() >> 1, lcd.height() >> 1); // 時計描画時の中心を画面中心に合わせる

  canvas.setColorDepth(lgfx::palette_4bit);  // 各部品を４ビットパレットモードで準備する
  clockbase.setColorDepth(lgfx::palette_4bit);
  needle1.setColorDepth(lgfx::palette_4bit);
  shadow1.setColorDepth(lgfx::palette_4bit);
  needle2.setColorDepth(lgfx::palette_4bit);
  shadow2.setColorDepth(lgfx::palette_4bit);
// パレットの初期色はグレースケールのグラデーションとなっており、
// 0番が黒(0,0,0)、15番が白(255,255,255)
// 1番～14番は黒から白へ段階的に明るさが変化している
//
// パレットを使う場合、描画関数は色の代わりに0～15のパレット番号を指定する

  canvas.createSprite(width, width); // メモリ確保
  clockbase.createSprite(width, width);
  needle1.createSprite(9, 119);
  shadow1.createSprite(9, 119);
  needle2.createSprite(3, 119);
  shadow2.createSprite(3, 119);

  canvas.fillScreen(transpalette); // 透過色で背景を塗り潰す (create直後は0埋めされているので省略可能)
  clockbase.fillScreen(transpalette);
  needle1.fillScreen(transpalette);
  shadow1.fillScreen(transpalette);

  clockbase.setTextFont(4);           // フォント種類を変更(時計盤の文字用)
  clockbase.setTextDatum(lgfx::middle_center);
  clockbase.fillCircle(halfwidth, halfwidth, halfwidth    ,  6); // 時計盤の背景の円を塗る
  clockbase.drawCircle(halfwidth, halfwidth, halfwidth - 1, 15);
  for (int i = 1; i <= 60; ++i) {
    float rad = i * 6 * - 0.0174532925;              // 時計盤外周の目盛り座標を求める
    float cosy = - cos(rad) * (halfwidth * 10 / 11);
    float sinx = - sin(rad) * (halfwidth * 10 / 11);
    bool flg = 0 == (i % 5);      // ５目盛り毎フラグ
    clockbase.fillCircle(halfwidth + sinx + 1, halfwidth + cosy + 1, flg * 3 + 1,  4); // 目盛りを描画
    clockbase.fillCircle(halfwidth + sinx    , halfwidth + cosy    , flg * 3 + 1, 12);
    if (flg) {                    // 文字描画
      cosy = - cos(rad) * (halfwidth * 10 / 13);
      sinx = - sin(rad) * (halfwidth * 10 / 13);
      clockbase.setTextColor(1);
      clockbase.drawNumber(i/5, halfwidth + sinx + 1, halfwidth + cosy + 4);
      clockbase.setTextColor(15);
      clockbase.drawNumber(i/5, halfwidth + sinx    , halfwidth + cosy + 3);
    }
  }
  clockbase.setTextFont(7);

  needle1.setPivot(4, 100);  // 針パーツの回転中心座標を設定する
  shadow1.setPivot(4, 100);
  needle2.setPivot(1, 100);
  shadow2.setPivot(1, 100);
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

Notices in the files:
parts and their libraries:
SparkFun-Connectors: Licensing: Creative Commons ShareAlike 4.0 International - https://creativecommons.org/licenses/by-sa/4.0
